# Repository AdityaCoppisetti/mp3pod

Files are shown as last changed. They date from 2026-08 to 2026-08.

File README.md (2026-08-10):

for the longest time i wanted to build a mp3 player and 
so i decided to build one using hackclub's macondo program which will also provide me funds
to build it. 
i absolutely love e ink display and decided to use that as i was also using it for my kindle project.
this is how my build looks like 



im a sucker for single purpose devices. 
i used to own a mp3 player when i was a little kid and i used to take that little nugget along with me everywhere. 
but then i lost it which was very unfortunate. 
hackclub's macondo program honestly just gave me a reason to make one. 

and i decided to make it also because it would help me improve my schematic , pcb understanding/ making skills 

here are some questions you must be wondering 
1) did i use ai for this project?
   - yes i kind of did use ai. i used it to make sure my wiring was correct by providing chatgpt screenshots and asking for feedback.
2) is there bluetooth?
   - yes the esp32 module im using has inbuilt bluetooth so i can connect my bluetooth headphones.
3) does it have storage?
   - yes ive put a sd card module and i will insert a sd card into it with my songs already loaded.
4) does it have wifi?
   - ayes the esp 32 module im using also has wifi.
5) can you listen to songs that you havent downloaded?
   - yes using wifi , i can build a ui and load all my songs into my home server and listen to music while connected to wifi anywhere i am.
6) what would happen if i run out of storage
   - i can load the songs that i am not able to download onto my home server and listen to it when the device is online.
7) how do you load songs onto it
   - you can load the songs onto the sd card or you could upload it onto the sd card via bluetooth or wifi using the esp32 module. 

ive gotten really good at building pcbs

Screenshot From 2026-08-10 12-37-03

Screenshot From 2026-08-10 12-24-52

Screenshot From 2026-08-10 12-10-29

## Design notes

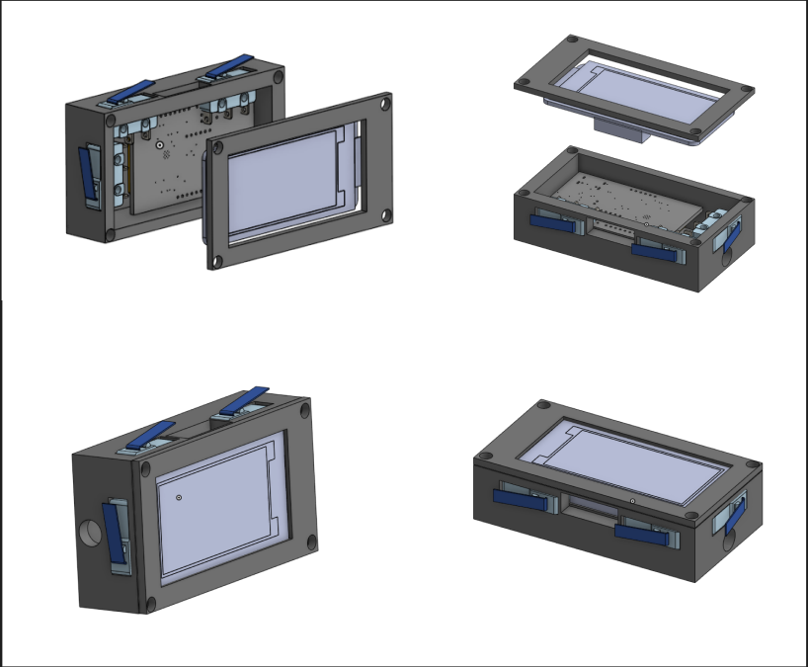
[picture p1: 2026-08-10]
preview.png

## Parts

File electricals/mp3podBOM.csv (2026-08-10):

Reference | KiCad Qty | Value | Footprint | Product | Purchase Qty | Currency | Unit Price | Pack/Line Price | Product Link | in usd
C1,C2,C3,C4,C5 | 25 | 4u7 | C_0805_2012Metric | 4.7µF 0805 SMD capacitor | 10 | INR | 14 | 140 | https://robu.in/product/mc0805f475z160ct-multicomp-pro-cap-smd-mlcc-4-7%c2%b5f-16-v-0805-pack-of-5/ | $1.47
C6 | 1 | C | C_0402_1005Metric | 4.7µF 0402 SMD capacitor | 5 | INR | 6 | 30 | https://robu.in/product/155r61a475meaad-murata-cap-smd-mlcc-4-7-%c2%b5f-10-v-0402-pack-of-1/ | $0.31
C9 | 1 | 4U7 | C_0805_2012Metric | 4.7µF 0805 SMD capacitor | 10 | INR | 14 | 140 | https://robu.in/product/mc0805f475z160ct-multicomp-pro-cap-smd-mlcc-4-7%c2%b5f-16-v-0805-pack-of-5/ | already have
C10 | 1 | 100N | C_0402_1005Metric | 100nF 0402 SMD capacitor | 5 | INR | 0.55 | 2.75 | https://robu.in/product/0402b104k500nt-fh-50v-100nf-x7r%c2%b110-0402-multilayer-ceramic-capacitors-mlcc-smd-smt-rohs/ | $0.03
C11 | 1 | 4.7u | C_0805_2012Metric | 4.7µF 0805 SMD capacitor | 10 | INR | 14 | 140 | https://robu.in/product/mc0805f475z160ct-multicomp-pro-cap-smd-mlcc-4-7%c2%b5f-16-v-0805-pack-of-5/ | already have
D1 | 1 | D | D_SOD-882D | PMEG3002AELD SOD-882D Schottky diode | 5 | INR | 10 | 50 | https://robu.in/product/pmeg3002aeld315-nexperia-30v-480mv200ma-200ma-sod-882d-schottky-diodes-rohs/ | $0.52
D2 | 1 | LED | LED_0402_1005Metric | 0402 red SMD LED | 5 | INR | 1.58 | 7.9 | https://robu.in/product/0402-surface-mount-led-red-50pcs/ | $0.08
J1 | 1 | USB_C_Receptacle_USB2.0_16P | USB_C_Receptacle_G-Switch_GT-USB-7010ASV | G-Switch GT-USB7010ASV USB-C receptacle | 1 | USD | 0.44 | 0.44 | https://jlcpcb.com/partdetail/GSwitch-GT_USB7010ASV/C2988369 | $0.44
J2 | 1 | Conn_01x02 | JST_PH_S2B-PH-K_1x02_P2.00mm_Horizontal | JST PH 2-pin 2.00mm horizontal connector | 5 | USD | 0.68 |  | https://robu.in/product/s2b-ph-klfsn-jst-1x2p-2p-ph-tin-2-25%e2%84%8385%e2%84%83-2a-1-2mm-brass-bend-insert-push-pullp2mm-wire-to-board-connector-rohs/ | $0.68
J3 | 1 | Conn_01x08_Pin | PinHeader_1x08_P2.00mm_Vertical | 1x8 2.00mm pitch pin header | 10 | USD | 0.42 | 4.2 | https://robu.in/product/ds1021-09-1x8sf1-a3-0-b6-0-b-connfly-1x8-pin-2-54mm-pin-header-v-t-type-h2-0mm/ | $0.42
J4,J5 | 4 | Conn_01x06_Pin | PinHeader_1x06_P2.00mm_Vertical | 1x6 2.00mm pitch pin header | 10 | USD | 0.42 |  | https://robu.in/product/ds1021-09-1x8sf1-a3-0-b6-0-b-connfly-1x8-pin-2-54mm-pin-header-v-t-type-h2-0mm/ | $0.42
R1,R2 | 4 | 5K1 | R_0402_1005Metric | 5.1kΩ 0402 SMD resistor | 5 | USD | 0.04 |  | https://robu.in/product/ac0402fr-075k1l-yageo-res-thick-film-0402-5-1k-ohm-1-0-063w1-16w-%c2%b1100ppm-c-pad-smd-t-r-automotive-aec-q200/ | $0.04
R3 | 1 | 0r | R_0402_1005Metric | 0Ω 0402 SMD resistor | 5 | USD | 0.013 |  | https://robu.in/product/erj2ge0r00x-panasonic-100mw-thick-film-resistors-100ppm-%e2%84%83600ppm-%e2%84%83-0%cf%89-0402-chip-resistor-surface-mount-rohs/ | $0.01
R4,R6,R8,R9 | 16 | 10k | R_0402_1005Metric | 10kΩ 0402 SMD resistor | 10 | USD | 0.082 |  | https://robu.in/product/10k-resistor-smdr-0402-pack-of-50/ | $0.08
R5 | 1 | 100r | R_0402_1005Metric | 100Ω 0402 SMD resistor | 2 |  |  |  | https://robu.in/product/1-month-warranty-1125/ | $0.03
R10 | 1 | 470r | R_0402_1005Metric | 470Ω 0402 SMD resistor | 3 | USD | 0.0068 |  | https://robu.in/product/ac0402fr-07470rl-yageo-res-thick-film-0402-470-ohm-1-0-063w1-16w-%c2%b1100ppm-c-pad-smd-t-r-automotive-aec-q200/ | $0.01
R11 | 1 | 470r | R_0805_2012Metric | 470Ω 0805 SMD resistor | 4 | USD | 0.042 |  | https://robu.in/product/rc0805fr-07470rl-yageo-res-thick-film-0805-470-ohm-1-0-125w1-8w-%c2%b1100ppm-c-pad-smd-t-r/ | $0.04
R12,R13,R14 | 9 | R | PinHeader_1x02_P2.00mm_Vertical | 1x2 2.00mm pitch pin header | 5 | USD | 0.42 |  | https://robu.in/product/ds1021-09-1x8sf1-a3-0-b6-0-b-connfly-1x8-pin-2-54mm-pin-header-v-t-type-h2-0mm/ | $0.42
SW1,SW2 | 4 | SW_Push | SW_SPST_B3U-1000P | Omron B3U-1000P SMD tactile switch | 6 | USD | 3.99 | 3.99 | https://robu.in/product/b3u-1000p-omron-2-5mm-1-6mm-round-button-50ma-vertical-welding-3mm-spst-1-53n-12v-smd2-5x3mm-tactile-switches-rohs/ | $3.99
SW3,SW4,SW5,SW6 | 16 | SW_Push | PinHeader_1x02_P2.00mm_Vertical | 1x2 2.00mm connector/header | 7 | USD | 0.23 |  | https://robu.in/product/aa07a09010000006a-bzcn-3a-125v-3a-250v-10000-times-plugin-limit-switches-rohs/ | $0.23
U1 | 1 | USBLC6-2SC6 | SOT-23-6 | USBLC6-2SC6 | 8 | USD | 0.47 |  | https://robu.in/product/usblc6-2sc6-ms-msksemi-4-5a-15v-150w-6v-5v-sot-23-6-esd-and-surge-protection-tvs-esd-rohs/ | $0.47
U2 | 1 | AP2112K-3.3 | SOT-23-5 | AP2112K-3.3 | 9 | USD | 0.94 |  | https://robu.in/product/ap2128k-3-3trg1-diodes-incorporated-300ma-fixed-3-3v-positive-6v-sot-23-5-voltage-regulators-linear-low-drop-out-ldo-regulators-rohs/ | $0.95
U3 | 1 | ESP32-C3-WROOM-02 | ESP32-C3-WROOM-02 | ESP32-C3-WROOM-02 | 10 | USD | 8.15 |  | https://robu.in/product/espressif-esp32-c3-wroom-02-n4-module/ | $8.15
U4 | 1 | MCP73831-2-OT | SOT-23-5 | MCP73831-2-OT | 11 | USD | 5.35 |  | https://robu.in/product/mcp73831t-2aci-ot-microchip-battery-charger-for-1-cell-of-li-ion-li-pol-battery-6v-input-4-2v-500ma-charge-sot-23-5/ | $5.35
BAT1 (external) |  | Lithium battery |  | SP Rechargeable battery (Amazon listing) | 12 | USD | 3.13 |  | https://www.amazon.in/SP-Rechargeable-Connector-Bluetooth-Electronics/dp/B0H568LR23 | $3.13
pcb from jlcpcb |  | pcb |  | pcb | 1 | USD | 2 | 2 |  | $2.00
shipping for pcb |  | pcb |  | pcb |  |  | 30 | 30 |  | $28.00
e ink display | 1 | e ink display | none | e ink display | 1 | USD | 13.35 | 13.35 | https://robu.in/product/2-13inch-e-ink-paper-display-hat-for-raspberry-pi-three-color/ | $13.35
 |  |  |  |  |  |  |  |  |  | The total is $70.62 USD.

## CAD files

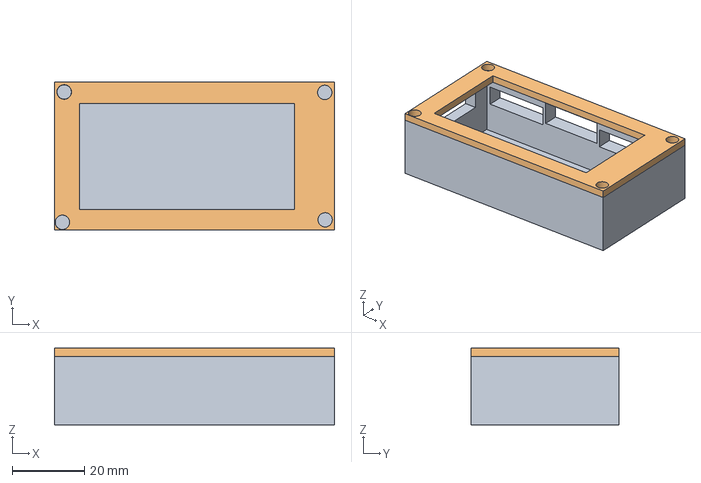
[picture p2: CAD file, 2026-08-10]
CAD/mp3pod case.step
77.5 x 40.9 x 21.2 mm

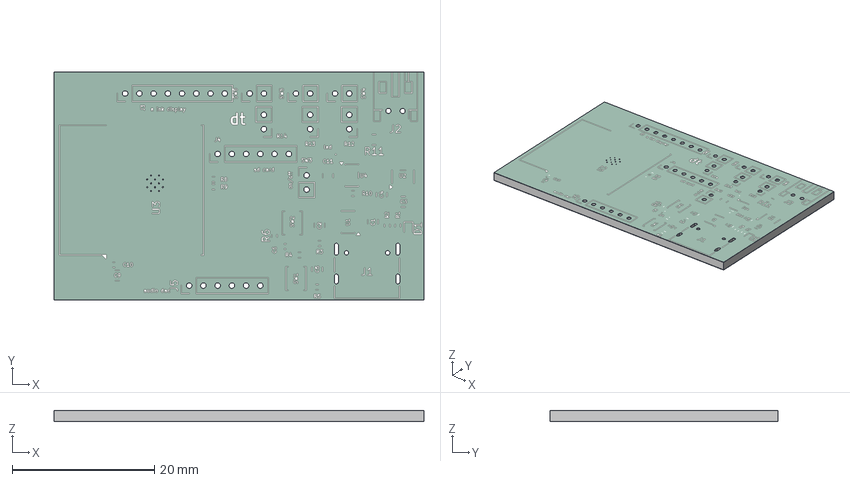
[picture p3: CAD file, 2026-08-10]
CAD/mp3pod.step
52.0 x 32.0 x 1.64 mm
mp3pod_silkscreen
mp3pod_soldermask x 2
mp3pod_PCB

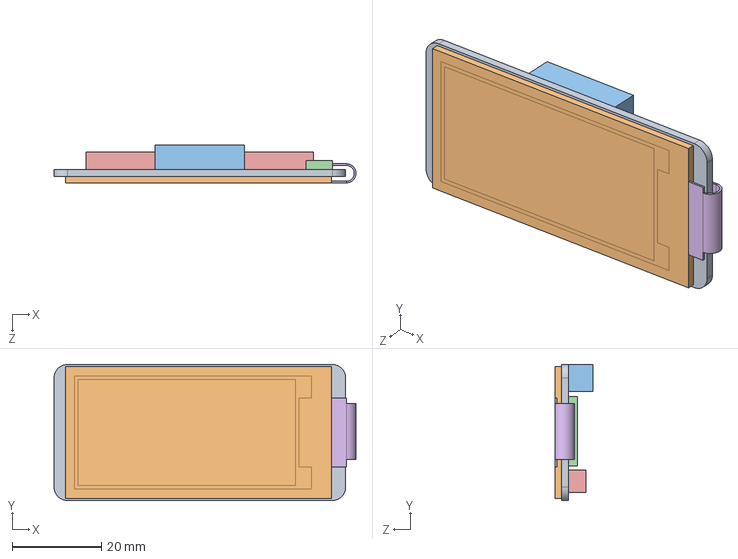
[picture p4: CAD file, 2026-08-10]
CAD/2.13inch e-Paper HAT bwr v3.STEP
67.5 x 30.4 x 8.47 mm

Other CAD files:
CAD/SD Card Module.x_t
CAD/limit switch.x_t

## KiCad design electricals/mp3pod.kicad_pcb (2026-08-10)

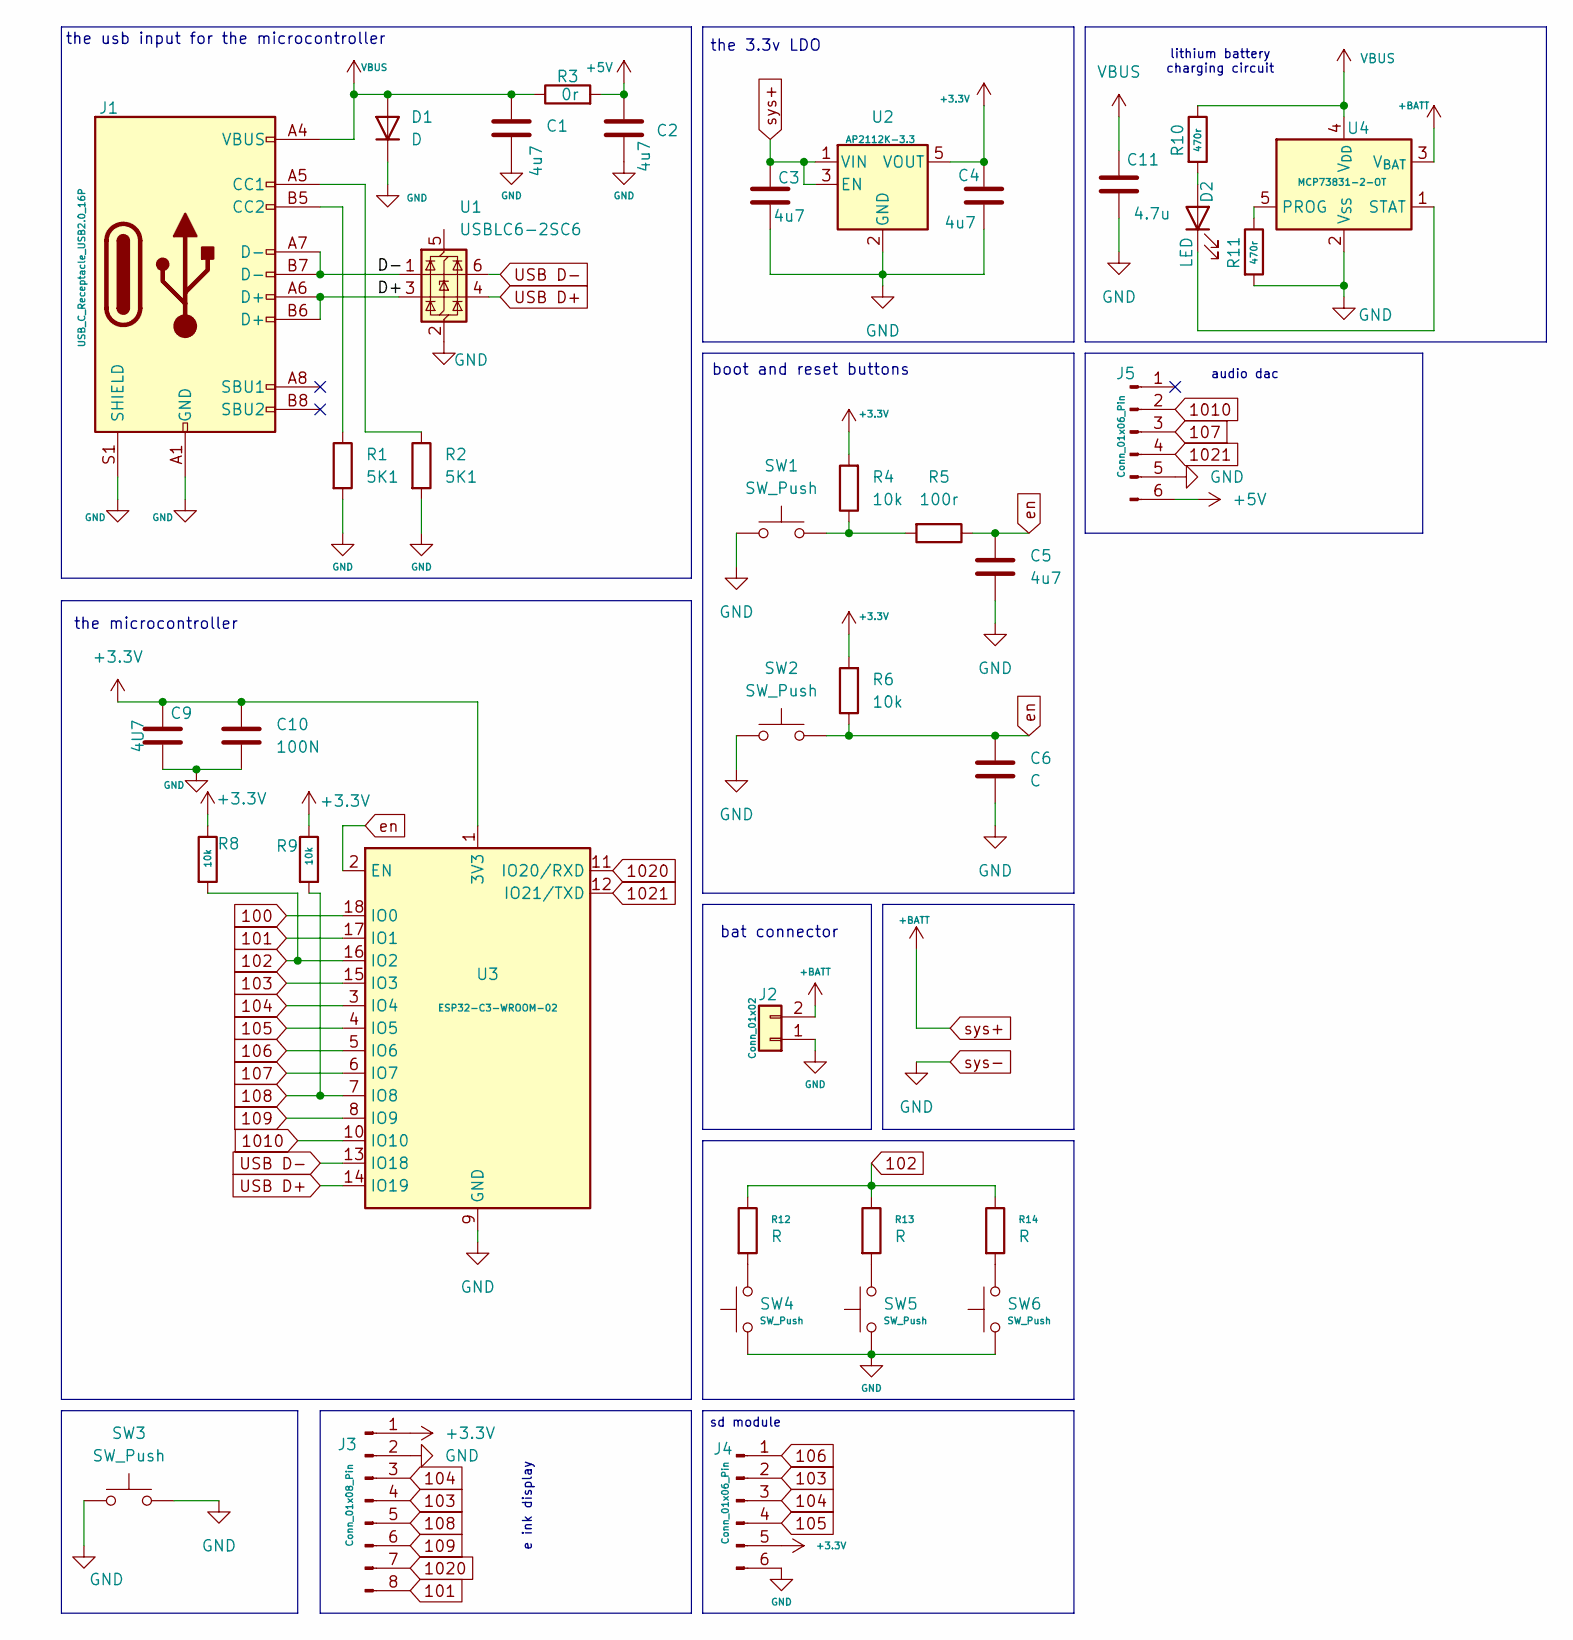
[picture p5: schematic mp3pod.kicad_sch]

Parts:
C1, C2, C3, C4, C5: 4u7; C_0805_2012Metric
C6: C; C_0402_1005Metric
C9: 4U7; C_0805_2012Metric
C10: 100N; C_0402_1005Metric
C11: 4.7u; C_0805_2012Metric
D1: D; D_SOD-882D
D2: LED; LED_0402_1005Metric
J1: USB_C_Receptacle_USB2.0_16P; USB_C_Receptacle_G-Switch_GT-USB-7010ASV
J2: Conn_01x02; JST_PH_S2B-PH-K_1x02_P2.00mm_Horizontal
J3: Conn_01x08_Pin; PinHeader_1x08_P2.00mm_Vertical
J4, J5: Conn_01x06_Pin; PinHeader_1x06_P2.00mm_Vertical
R1, R2: 5K1; R_0402_1005Metric
R3: 0r; R_0402_1005Metric
R4, R6, R8, R9: 10k; R_0402_1005Metric
R5: 100r; R_0402_1005Metric
R10: 470r; R_0402_1005Metric
R11: 470r; R_0805_2012Metric
R12, R13, R14: R; PinHeader_1x02_P2.00mm_Vertical
SW1, SW2: SW_Push; SW_SPST_B3U-1000P
SW3, SW4, SW5, SW6: SW_Push; PinHeader_1x02_P2.00mm_Vertical
U1: USBLC6-2SC6; SOT-23-6
U2: AP2112K-3.3; SOT-23-5
U3: ESP32-C3-WROOM-02
U4: MCP73831-2-OT; SOT-23-5

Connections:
100: U3.18 (IO0)
101: J3.8, U3.17 (IO1)
102: R8.2, R12.1, R13.1, R14.1, U3.16 (IO2)
103: J3.4, J4.2, U3.15 (IO3)
104: J3.3, J4.3, U3.3 (IO4)
105: J4.4, U3.4 (IO5)
106: J4.1, U3.5 (IO6)
107: J5.3, U3.6 (IO7)
108: J3.5, R9.2, U3.7 (IO8)
109: J3.6, U3.8 (IO9)
1010: J5.2, U3.10 (IO10)
1020: J3.7, U3.11 (IO20/RXD)
1021: J5.4, U3.12 (IO21/TXD)
+3.3V: C4.1, C9.1, C10.1, J3.1, J4.5, R4.2, R6.2, R8.1, R9.1, U2.5 (VOUT), U3.1 (3V3)
+5V: C2.1, J5.6, R3.2
/D+: J1.A6 (D+), J1.B6 (D+), U1.3 (I/O2)
/D-: J1.A7 (D-), J1.B7 (D-), U1.1 (I/O1)
unnamed 17: D2.2 (A), R10.2; also elsewhere on the board
unnamed 18: D2.1 (K), U4.1 (STAT); also elsewhere on the board
unnamed: J1.A5 (CC1), R2.1
unnamed: J1.B5 (CC2), R1.1
unnamed: R4.1, R5.2, SW1.2
unnamed: R12.2, SW4.2
unnamed: R13.2, SW5.2
unnamed: R14.2, SW6.2
unnamed: R11.1, U4.5 (PROG)
USB D+: U1.4 (I/O2), U3.14 (IO19)
USB D-: U1.6 (I/O1), U3.13 (IO18)
VBUS: C1.1, C11.1, D1.2 (A), J1.A4 (VBUS), J1.A9 (VBUS), J1.B4 (VBUS), J1.B9 (VBUS), R3.1, R10.1, U4.4 (V_{DD})
en: C5.1, C6.1, R5.1, R6.1, SW2.2, U3.2 (EN)
sys+: C3.1, J2.2, U2.1 (VIN), U2.3 (EN), U4.3 (V_{BAT})
sys-: C1.2, C2.2, C3.2, C4.2, C5.2, C6.2, C9.2, C10.2, C11.2, D1.1 (K), J1.A1 (GND), J1.A12 (GND), J1.B1 (GND), J1.B12 (GND), J1.S1 (SHIELD), J2.1, J3.2, J4.6, J5.5, R1.2, R2.2, R11.2, SW1.1, SW2.1, SW3.1, SW3.2, SW4.1, SW5.1, SW6.1, U1.2 (GND), U2.2 (GND), U3.9 (GND), U3.19 (GND), U4.2 (V_{SS})

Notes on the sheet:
bat connector
the 3.3v LDO
audio dac
the usb input for the microcontroller
lithium battery charging circuit
boot and reset buttons
e ink display
sd module
the microcontroller

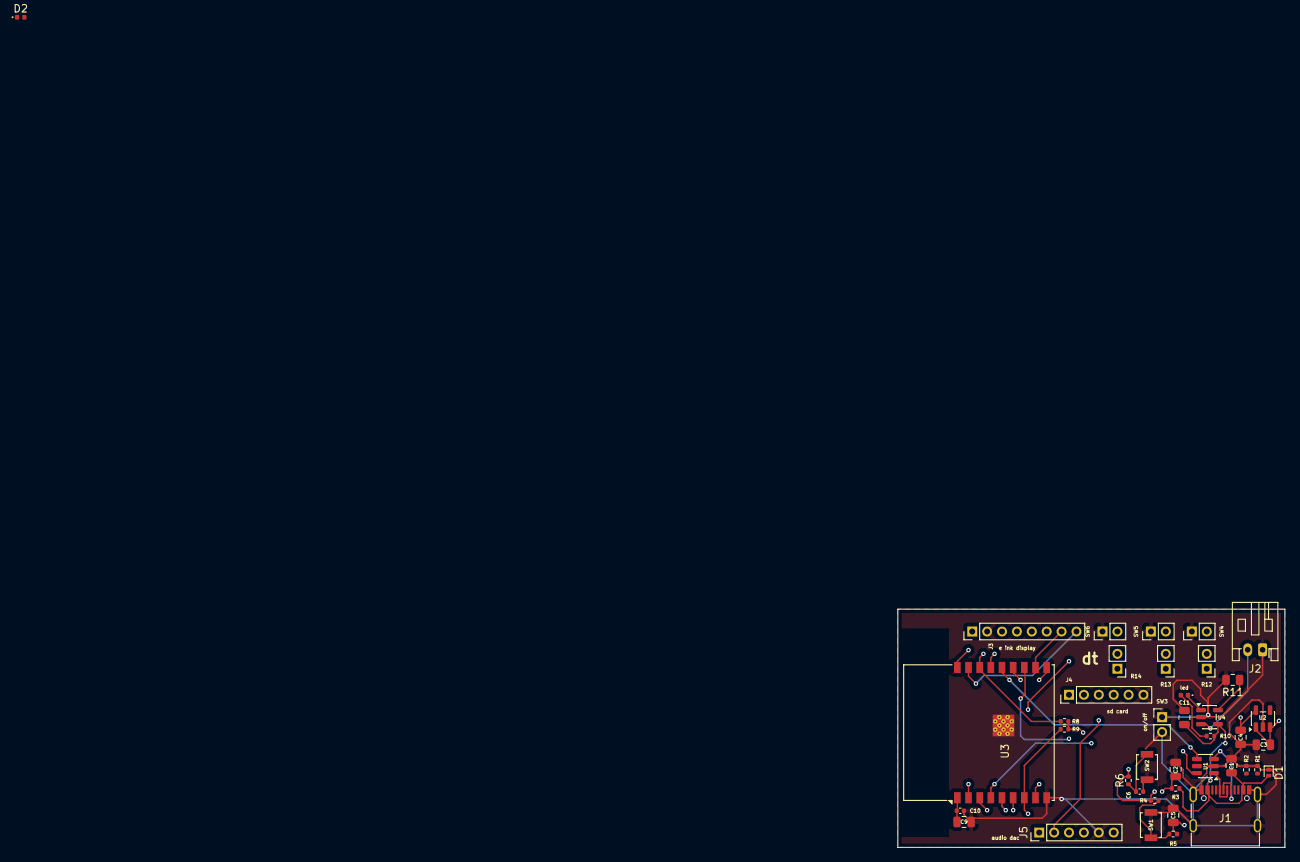
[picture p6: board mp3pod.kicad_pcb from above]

Board: 4 copper layers, 52.0 x 32.0 mm, 40 parts (0 on the bottom side), 31 nets.

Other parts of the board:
led: LED; LED_0402_1005Metric

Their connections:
unnamed 17: led.2 (A); also elsewhere on the board
unnamed 18: led.1 (K); also elsewhere on the board

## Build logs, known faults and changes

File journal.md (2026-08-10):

i remember my sister used to have a really small mp3 player and i got it when she got a a phone , thus not needing the mp3 player,
i remembering adding songs to it with the help of my older cousin brother and then listening to music everywhere i went - school ,tution , bus rides you name it i took it there 
but then i shortly after lost and i never found it again :(

i remember how good one purpose tech used to be in that era. 
i recently took a lil visit to that era when i got my hands on my ps2. 
tearing it down to clean it , respraying the case a better colour and restoring it. 
along the way i fell in love with old technology.
i got myself a few playstaion portable and restored them all and jailbroke them and wrote custom 
hombrew apps for them. 

i first wanted to build a custom homebrew app for my psp go and make it into a handy mp3 player
as it has bluetooth and a audio jack so that would be really cool. but then my psp go broke and i couldnt do that.

for the longest time i have been meaning to buy a old ipod classic and restoring it and jailbreaking and modding it 
but then i thought why not make my own mp3player? 
and so i began on the short journey of making the pcb for it.

i was in the same duration making a kindle and thus i had that "e ink display fever" 
i.e meaning i was in love with e ink displays and so i decided to use an e ink display

when i began i lowk just started designing without much of a design in my head. 

## The display 

okay so i will be using this e ink display - 



this is the Waveshare 2.13inch E-Ink Paper display HAT for Raspberry Pi, Three-Color
which is honesly so exciting to use.
this is made for the raspberry pi however there are pins given so i can use it with the esp32 aswell



okay so here is more info on the e ink display -

# interface :- 
1) VCC	3.3V/5V
2) GND	Ground
3) DIN	SPI MOSI pin
4) CLK	SPI SCK pin
5) CS	SPI chip selection, low active
6) DC	Data/Command selection (high for data, low for command)
7) RST	External reset, low active
8) BUSY	Busy status output, high active

a total of 8 pins , 6 pins excluding the vcc and gnd 

# specifications :-

1) Model No. / Name:	Display HAT
2) Display Size (Inch):	2.13
3) Display Resolution (pixel)	212 × 104
4) Display Color	Red, Black and White
5) Operating Voltage (V):	3.3
6) Outline dimension (mm)	65 × 30.2
7) Dot Pitch	0.229 × 0.228
8) Grey level	2
9) Viewing Angle (Deg.)	&gt;170°
10) Interface:	3-wire SPI, 4-wire SPI
11) Full Refresh Time (s)	15
12) Refresh Power	26.4mW(typ.)
13) Standby Power (mW)	&lt;0.017
14) Dimensions (L x W x H) mm	65 x 31 x 8
15) Weight (g):	20

this info i got from robu.in 

# the microcontroller - 

Im using the ESP32-C3-WROOM-02



using this board ill be making my own board with required gpio pins and boot and reset button

# specifications:-

1) Frequency (GHz):	2.4
2) Data Transfer Rate	150Mbps
3) Sensitivity (dBm):	-105
4)
5) Supply Voltage	3 to 3.6Mounting Type:	Surface Mount
6) Operating Temperature (°C):	-40 to 85
7) Memory Capacity	384KB ROM, 400KB SRAM, 4MB Flash

also got the above info from robu.in 

# the audio dac



# Specifications :

1) Product Type : I2S DAC Audio Decoder Module
2) Model : GY-PCM5102
3) DAC Chip : PCM5102A
4) Audio Interface : I2S
5) Input Interface : 3-Pin I2S
6) Audio Output : 3.5mm Stereo Jack
7) Audio Resolution : 16-Bit / 24-Bit / 32-Bit
8) Output Channel : Stereo
9) Operating Voltage : 5V DC
10) Form Factor : PHAT Format
11) Compatibility : Raspberry Pi & I2S Compatible Devices
12) Signal Type : Digital Audio Input
13) Output Type : Analog Stereo Audio
14) Mounting Type : Board Mount
15) Communication Protocol : I2S
16) Power Supply : 5V DC
17) Dimensions : 32 x 18 mm

 # the sd card module 
 
 
 which is honestly just a normal sd card module 

 its wired like this-

 

and then the switched, at first i was using the touch capacitive buttons but when i was designing the case for the kindle im making , which used them , i realised that it makes the entire case wayyyy tooo big and i would rather my mp3 player be slim

# the multifunctional buttons



okay so im using these buttons because they are slim tiny and i really like the satisfying click they have. 

they are multifunctional because i will use them for everything i.e - play , pause , next , volume up , volume down. 

now lets get onto making the schematic

i actually made this earlier and documented it  but it was super super bad 



okay so i just made the microcontroller again 



okay so ive added the lithium battery charger aswell 



finally added all the components im having a terrible migraine 



## august 10th 

yesterday i didnt complete the pcb fully but today i am. 

okay so apparently i didnt connect the pins to any of my modules so i just did that 

here is how i wired everything 

Screenshot From 2026-08-10 11-16-31

and then 

Screenshot From 2026-08-10 11-15-11

and then 

Screenshot From 2026-08-10 11-14-45

and then finally - 

Screenshot From 2026-08-10 11-15-28

okay so i removed the crystal because apparently the esp32 module already has a inbuilt crystal so i didnt really need that . so thats cool ig 

# the pcb - 
the pcb after all the routing looks like this. ( i dont want to redesign again )



and then 



in 3d view it looks like this

Screenshot From 2026-08-10 12-20-11

and then a lil 360- 

https://github.com/user-attachments/assets/797977f9-f8a4-482c-8bfa-8ac84a7257ed

ive made this pcb 3 times now and just look at how much ive improved

version 1- 



version 2 - 



and this was a whole mess , the pins were wired wrong and then there were 2 usb ports one for charging and one for data transfer and then all the refrences and values were butchered

and then the version 3 ( the latest version i just designed)



okay so here is what im gonna do- 
im going to export the pcb from kicad in .step and then import it into onshape along with other parts and then designed the case

okay so i deisgned the case and i got all the components , now i need to design the mockup 



it seems that i need to make the case a little more thick which is honestly alright and not a problem.

here is how it looks



keep in mind that i wont keep the limit switches like that , i wont have the flap like that and secondly ill cut its terminals with a cutter and use solder to connect the pins and make sure it doesnt touch anything. 



oh and i went ahead and added a small hole so i can put the audio jack there . ill desolder it from the audio dac board and then put it in the case and then solder it.

Screenshot From 2026-08-10 15-08-33

Screenshot From 2026-08-10 15-08-45

Screenshot From 2026-08-10 15-10-20

i finally did the most draining part of this entire process, i made a bill of material file in .csv 
it was extremely draining 



and now finally the project is at pause till the parts arrive and then ill continue this project
